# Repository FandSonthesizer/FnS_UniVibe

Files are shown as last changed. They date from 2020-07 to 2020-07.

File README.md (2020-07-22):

# FnS_UniVibe

A Univibe Clone using a white LED. This is a modern version of a univibe clone, instead of using a 15V lamp we use a white LED. This requested to modify the lamp driver circuit so now a dual opamp is driving it. We are using LDR03 for the light depending resistors, but a wide variety of LDRs will work too. Any standard Dual-Opamp will do.

The LDR's are so sensitive, that we have to dim the white LED quite a lot. A 47k resistor just brings the brightness down enough. Who would have thought... This should really bring down the power consumption compared to the original module.

Adapt the circuit to other LDR's by playing around with R58.

Check out our youtube channel: FatherandSonthesizer for a detailed demo of this cool module. (Though we use it in a synth rack...)

The PCB is prepared for the Vodoovibe and Resley Tone mod. Just do not populate C7, C12, C16 and C19. Instead follow the second link on the schematic and wire the caps on the 4P3T switch. connect using J12 and an 8pol cable. If you do not want the mod, ignore J12 and just populate the board as shown in the schematic.

Please note, that we forgot the true bypass switch on our front panel design. Maybe someone can come up with a better design, we would love to include it here.

The output signal of the module is somewhat less in volume than the input signal. A 2nd opamp takes care of that. A potentiometer on the front panel allows to adjust that volume.

For the led, LDR combination we created a symbol and a foot print for Kicad. Both are included in this repository. Make sure to configure your Kicad to make use of them. That symbol is called FnSVibeC, the foot print is in the NilsParts.pretty lib. Since no ambient light should reach the foto resistors we used a 3d-printer to print a housing for this part. Just a hollow square box, useing black PLA. (1mm wall)

The sound of this module is just awsome, make sure to check out youtube video. A guitar pedal version will follow later.

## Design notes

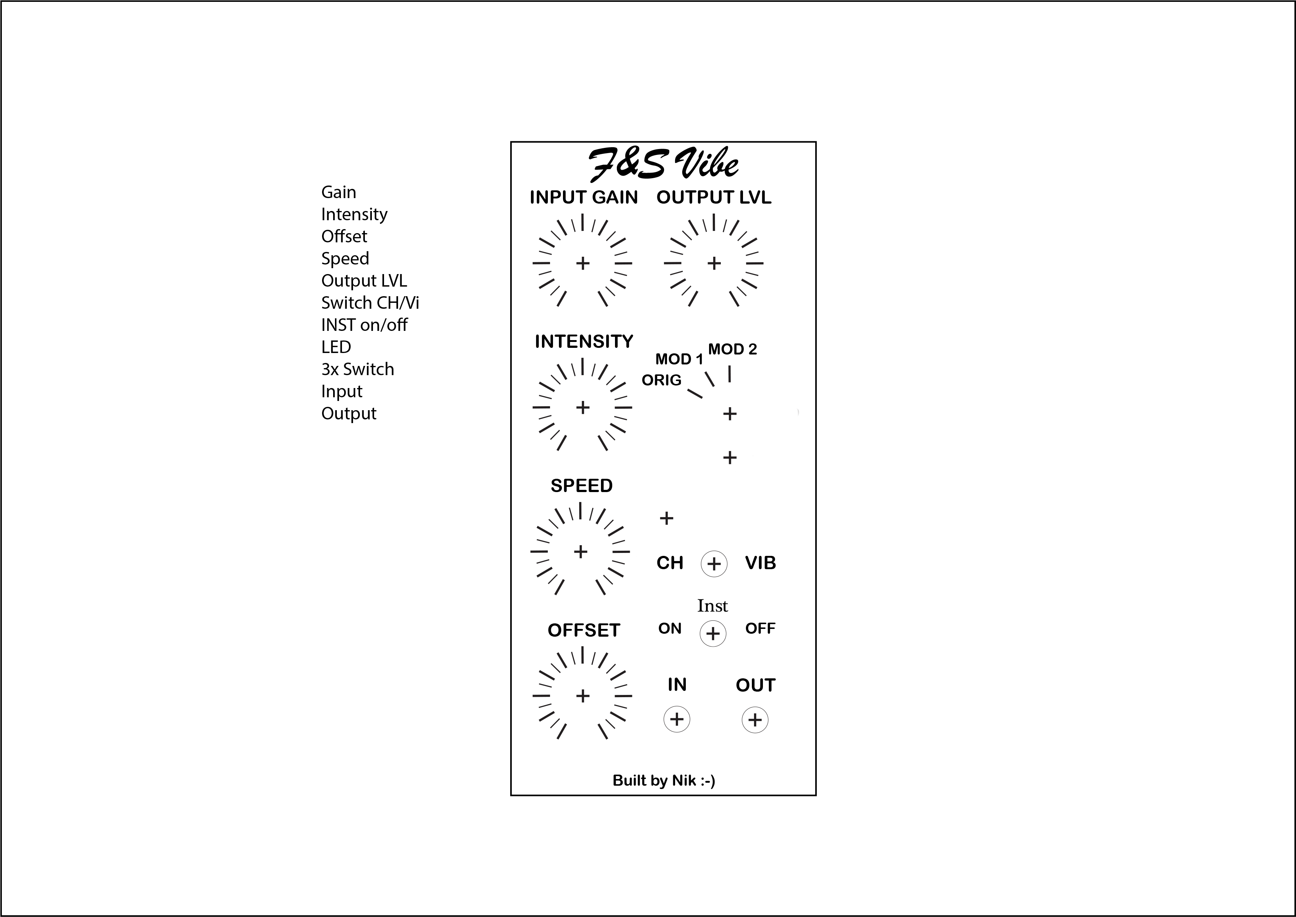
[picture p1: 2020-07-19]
FuS_UniVibe_V2/Univibe Faceplate.png

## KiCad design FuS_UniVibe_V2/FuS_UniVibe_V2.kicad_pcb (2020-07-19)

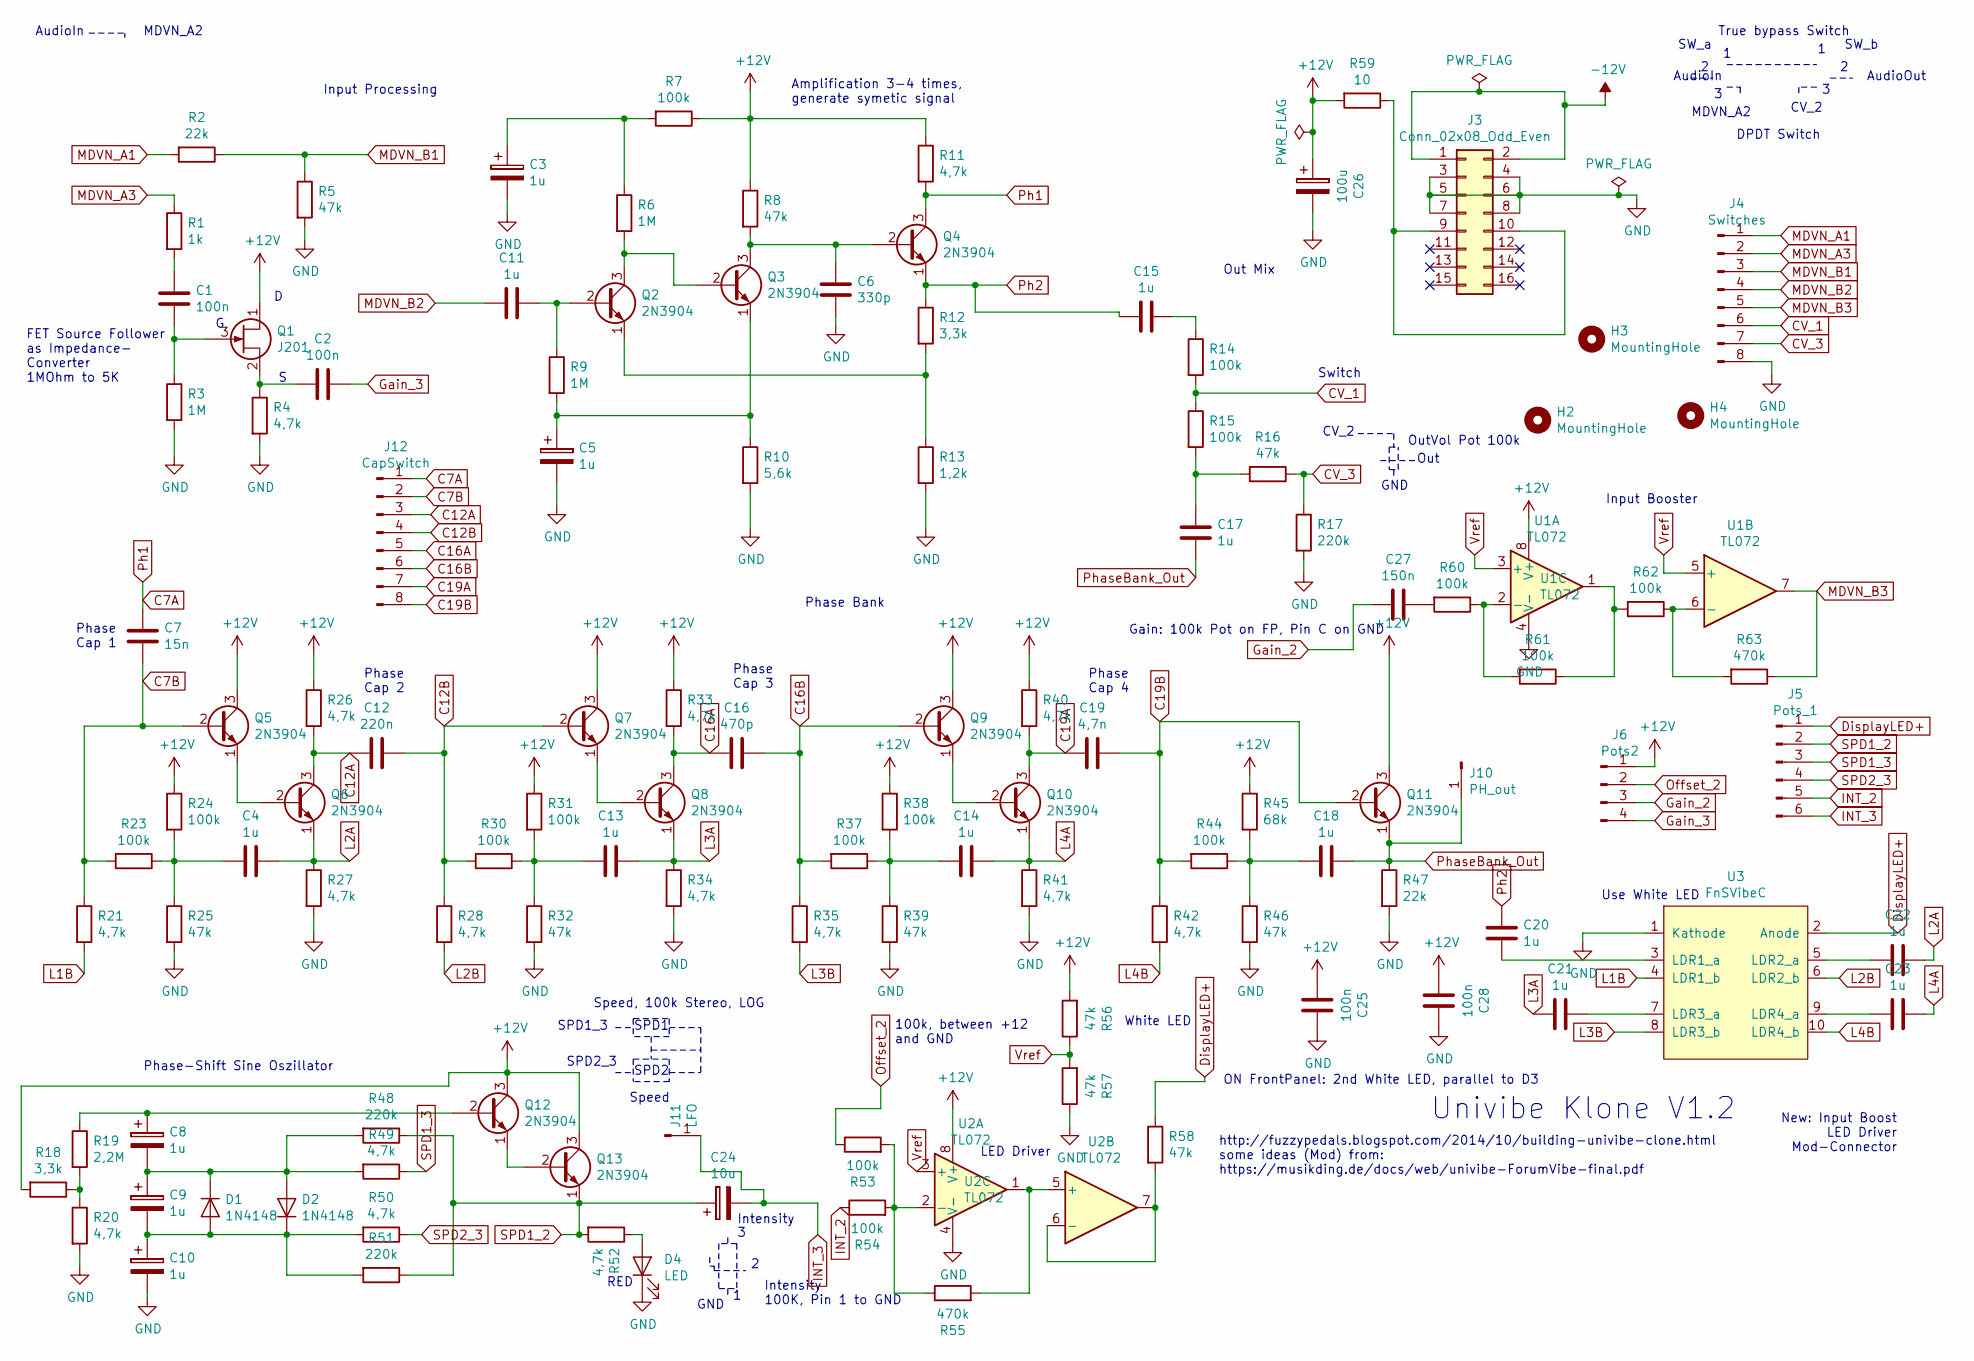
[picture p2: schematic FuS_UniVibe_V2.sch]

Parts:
C1, C2, C25, C28: 100n; Kondensator_Keramik
C3, C5, C8, C9, C10: 1u; Elko_D6.3mm_P2.50mm
C4, C11, C13, C14, C15, C17, C18, C20, C21, C22, C23: 1u; BIPolar_Elko_D6.3mm_P2.50mm
C6: 330p; Kondensator_Keramik
C7: 15n; Kondensator_Keramik
C12: 220n; Kondensator_Keramik
C16: 470p; Kondensator_Keramik
C19: 4,7n; Kondensator_Keramik
C24: 10u; Elko_D6.3mm_P2.50mm
C26: 100u; Elko_D6.3mm_P2.50mm
C27: 150n; Kondensator_Keramik
D1, D2: 1N4148; Diode_Horizontal
D4: LED; LED_Vertikal
H2, H3, H4: MountingHole; MountHole
J3: Conn_02x08_Odd_Even; PinHeader_2x08_P2.54mm_Vertical
J4: Switches; PinHeader_1x08_P2.54mm_Vertical
J5: Pots_1; PinHeader_1x06_P2.54mm_Vertical
J6: Pots2; PinHeader_1x04_P2.54mm_Vertical
J10: PH_out; Stift
J11: LFO; Stift
J12: CapSwitch; PinHeader_1x08_P2.54mm_Vertical
Q1: J201; TO-92_Wide
Q2, Q3, Q4, Q5, Q6, Q7, Q8, Q9, Q10, Q11, Q12, Q13: 2N3904; TO-92_Wide
R1: 1k; Widerstand_liegend
R2, R47: 22k; Widerstand_liegend
R3, R6, R9: 1M; Widerstand_liegend
R4, R11, R20, R21, R26, R27, R28, R33, R34, R35, R40, R41, R42, R49, R50, R52: 4,7k; Widerstand_liegend
R5, R8, R16, R25, R32, R39, R46, R56, R57, R58: 47k; Widerstand_liegend
R7, R14, R15, R23, R24, R30, R31, R37, R38, R44, R53, R54, R60, R61, R62: 100k; Widerstand_liegend
R10: 5,6k; Widerstand_liegend
R12, R18: 3,3k; Widerstand_liegend
R13: 1,2k; Widerstand_liegend
R17, R48, R51: 220k; Widerstand_liegend
R19: 2,2M; Widerstand_liegend
R45: 68k; Widerstand_liegend
R55, R63: 470k; Widerstand_liegend
R59: 10; Widerstand_liegend
U1, U2: TL072; DIP-8_W7.62mm_Socket_LongPads
U3: FnSVibeC; FnSVibe

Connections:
+12V: C25.2, C26.1, C28.2, J6.1, Q1.1 (D), Q5.3 (C), Q7.3 (C), Q9.3 (C), Q11.3 (C), Q12.3 (C), Q13.3 (C), R7.1, R8.1, R11.1, R18.2, R24.1, R26.1, R31.1, R33.1, R38.1, R40.1, R45.1, R56.2, R59.2, U1.8 (V+), U2.8 (V+)
-12V: J3.1, J3.2
C7A: C7.1, J12.1, Q4.3 (C), R11.2
C7B: C7.2, J12.2, Q5.2 (B), R21.1, R23.2
C12A: C12.2, J12.3, Q6.3 (C), R26.2
C12B: C12.1, J12.4, Q7.2 (B), R28.1, R30.2
C16A: C16.2, J12.5, Q8.3 (C), R33.2
C16B: C16.1, J12.6, Q9.2 (B), R35.1, R37.2
C19A: C19.2, J12.7, Q10.3 (C), R40.2
C19B: C19.1, J12.8, Q11.2 (B), R42.1, R44.2
CV_1: J4.6, R14.2, R15.1
CV_3: J4.7, R16.1, R17.1
DisplayLED+: J5.1, R58.1, U3.2 (Anode)
GND: C3.2, C5.2, C6.2, C10.2, C25.1, C26.2, C28.1, D4.1 (K), J3.3, J3.4, J3.5, J3.6, J3.7, J3.8, J4.8, R3.2, R4.2, R5.2, R10.2, R13.2, R17.2, R20.2, R25.2, R27.2, R32.2, R34.2, R39.2, R41.2, R46.2, R47.2, R57.1, U1.4 (V-), U2.4 (V-), U3.1 (Kathode)
Gain_2: C27.2, J6.3
Gain_3: C2.1, J6.4
INT_2: J5.5, R54.1
INT_3: C24.2, J5.6, J11.1
L1B: R21.2, U3.4 (LDR1_b)
L2A: C4.1, C22.2, Q6.1 (E), R27.1
L2B: R28.2, U3.6 (LDR2_b)
L3A: C13.1, C21.1, Q8.1 (E), R34.1
L3B: R35.2, U3.8 (LDR3_b)
L4A: C14.1, C23.2, Q10.1 (E), R41.1
L4B: R42.2, U3.10 (LDR4_b)
MDVN_A1: J4.1, R2.2
MDVN_A3: J4.2, R1.1
MDVN_B1: J4.3, R2.1, R5.1
MDVN_B2: C11.2, J4.4
MDVN_B3: J4.5, R63.1, U1.7
unnamed: C1.1, R1.2
unnamed: C1.2, Q1.3 (G), R3.1
unnamed: C2.2, Q1.2 (S), R4.1
unnamed: C3.1, R6.1, R7.2
unnamed: C4.2, R23.1, R24.2, R25.1
unnamed: C5.1, Q3.1 (E), R9.2, R10.1
unnamed: C6.1, Q3.3 (C), Q4.2 (B), R8.2
unnamed: C8.1, Q12.2 (B), R19.1
unnamed: C8.2, C9.1, D1.1 (K), D2.2 (A), R48.2, R49.2
unnamed: C9.2, C10.1, D1.2 (A), D2.1 (K), R50.2, R51.2
unnamed: C11.1, Q2.2 (B), R9.1
unnamed: C13.2, R30.1, R31.2, R32.1
unnamed: C14.2, R37.1, R38.2, R39.1
unnamed: C15.1, R14.1
unnamed: C17.2, R15.2, R16.2
unnamed: C18.2, R44.1, R45.2, R46.1
unnamed: C20.1, U3.3 (LDR1_a)
unnamed: C21.2, U3.7 (LDR3_a)
unnamed: C22.1, U3.5 (LDR2_a)
unnamed: C23.1, U3.9 (LDR4_a)
unnamed: C27.1, R60.2
unnamed: D4.2 (A), R52.1
unnamed: J3.9, J3.10, R59.1
unnamed: Q2.1 (E), R12.2, R13.1
unnamed: Q2.3 (C), Q3.2 (B), R6.2
unnamed: Q5.1 (E), Q6.2 (B)
unnamed: Q7.1 (E), Q8.2 (B)
unnamed: Q9.1 (E), Q10.2 (B)
unnamed: Q12.1 (E), Q13.2 (B)
unnamed: R18.1, R19.2, R20.1
unnamed: R53.2, R54.2, R55.1, U2.2 (-)
unnamed: R55.2, U2.1, U2.5 (+)
unnamed: R58.2, U2.6 (-), U2.7
unnamed: R60.1, R61.2, U1.2 (-)
unnamed: R61.1, R62.2, U1.1
unnamed: R62.1, R63.2, U1.6 (-)
Offset_2: J6.2, R53.1
Ph2: C15.2, C20.2, Q4.1 (E), R12.1
PhaseBank_Out: C17.1, C18.1, J10.1, Q11.1 (E), R47.1
SPD1_2: C24.1, J5.2, Q13.1 (E), R48.1, R51.1, R52.2
SPD1_3: J5.3, R49.1
SPD2_3: J5.4, R50.1
Vref: R56.1, R57.2, U1.3 (+), U1.5 (+), U2.3 (+)

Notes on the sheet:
AudioIn
MDVN_A2
CV_2
GND
Out
OutVol Pot 100k
Input Processing
Out Mix
Phase Bank
Phase-Shift Sine Oszillator
SPD1
SPD2
SPD1_3
SPD2_3
Speed, 100k Stereo, LOG
Intensity 100K, Pin 1 to GND
Switch
Univibe Klone V1.2
http://fuzzypedals.blogspot.com/2014/10/building-univibe-clone.html some ideas (Mod) from: https://musikding.de/docs/web/univibe-ForumVibe-final.pdf
White LED
Speed
FET Source Follower as Impedance- Converter 1MOhm to 5K
Amplification 3-4 times, generate symetic signal
Phase Cap 1
Phase Cap 2
Phase Cap 3
Phase Cap 4
Intensity
100k, between +12 and GND
ON FrontPanel: 2nd White LED, parallel to D3
RED
True bypass Switch
SW_a
SW_b
DPDT Switch
AudioOut
Input Booster
Gain: 100k Pot on FP, Pin C on GND
New: Input Boost LED Driver Mod-Connector
LED Driver

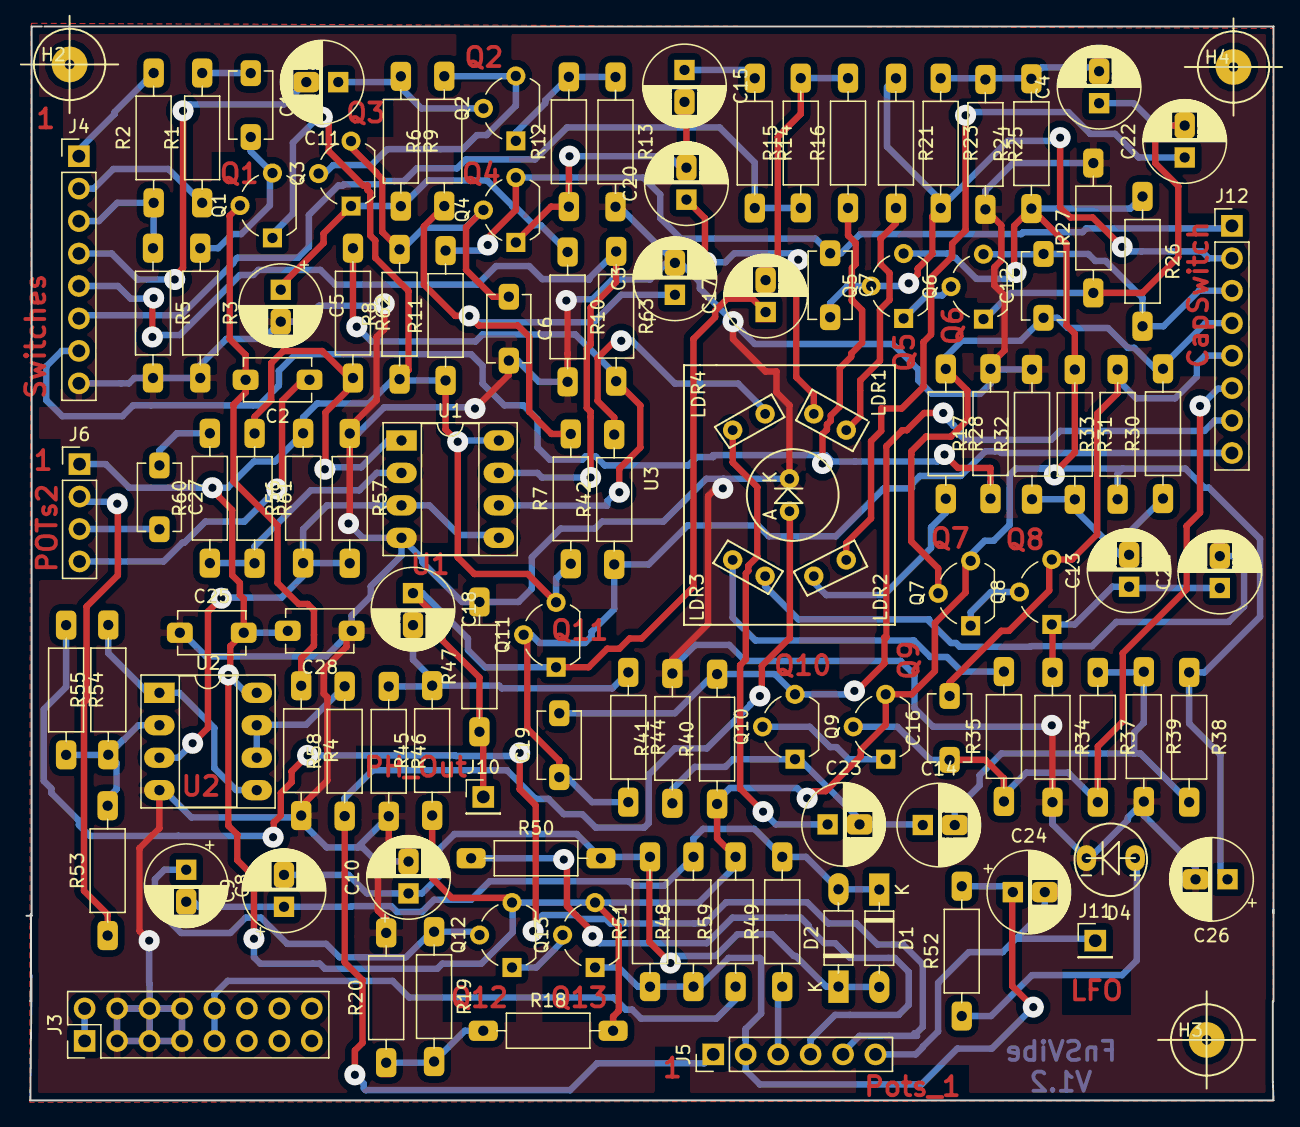
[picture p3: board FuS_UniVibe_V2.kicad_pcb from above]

Board: 2 copper layers, 97.6 x 84.0 mm, 116 parts (0 on the bottom side), 73 nets.
